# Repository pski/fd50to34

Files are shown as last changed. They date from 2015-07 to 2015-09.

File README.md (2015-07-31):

# fd50to34: Adapt 34 Pin Floppy Drives to 50 Pin Controllers
## by Mark J. Blair <nf6x@nf6x.net>

This board is a cable adapter to allow 3.5" or 5.25" floppy disk drives to be connected to computer systems with floppy disk controllers that are designed for use with 8" floppy disk drives. It is inspired by instructions by Frank Durda IV for connecting 5.25" floppy disk drives to Radio Shack/Tandy model II, 12, 16 and 6000 computers, as found at this URL:

http://nemesis.lonestar.org/computers/tandy/hardware/model16_6000/floppyfix.html

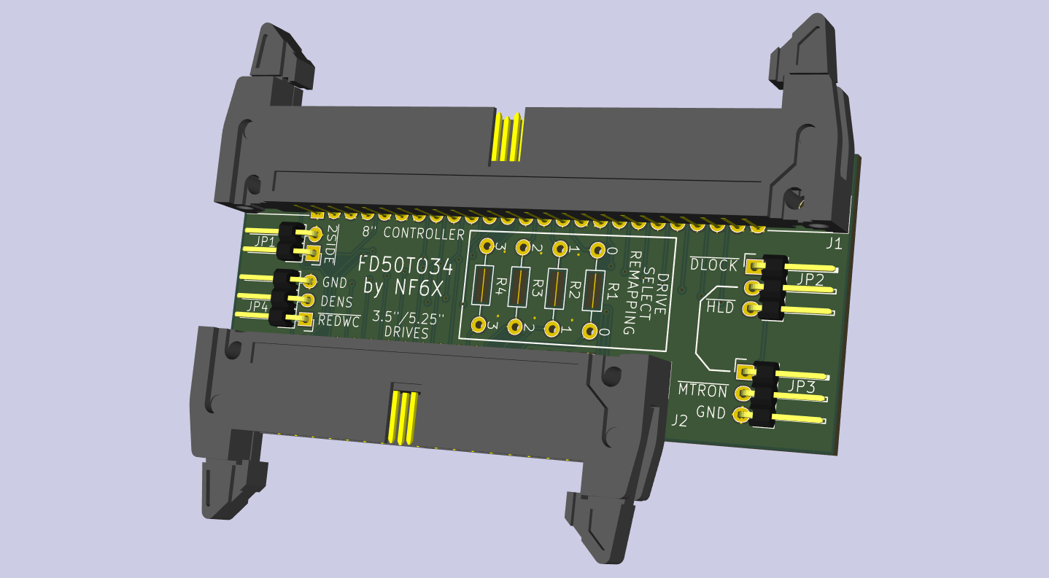
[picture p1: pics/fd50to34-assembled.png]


## Features

* Jumper-selectable double-sided disk support.
* Jumper selection allows drive motors to be strapped on all the time, or controlled by either the head load or in-use/door-lock signal.
* Bank of shorted resistor footprints allows easy drive select number remapping.
* Drive signals are labeled on bottom of board for debugging purposes.

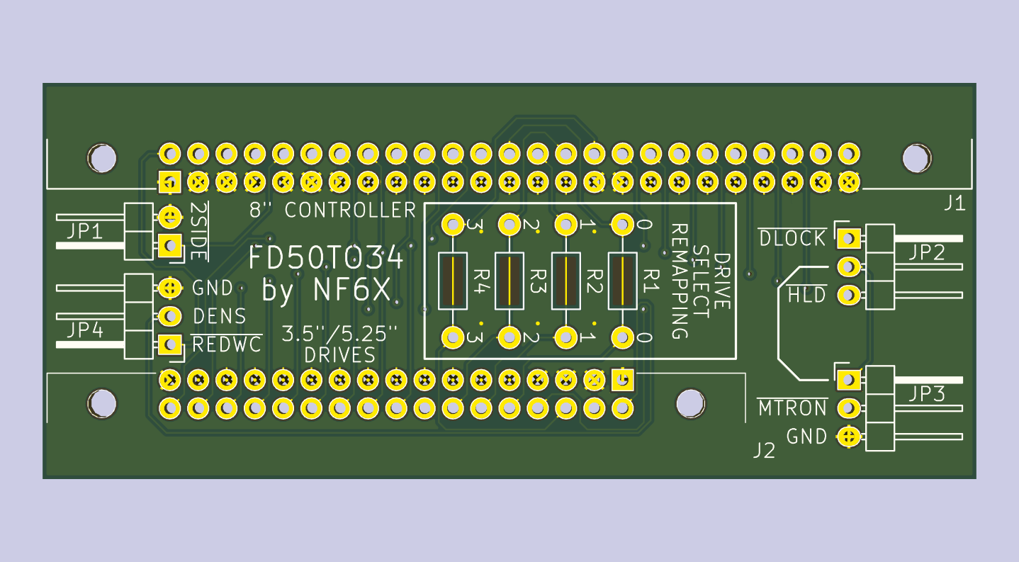
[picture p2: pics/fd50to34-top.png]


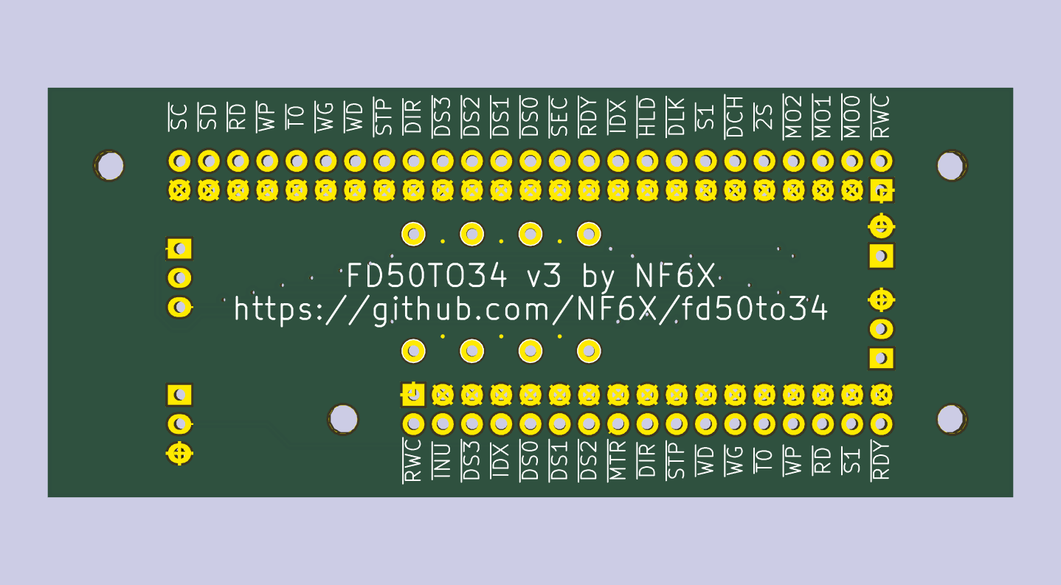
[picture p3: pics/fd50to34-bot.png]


## Schematic Diagram

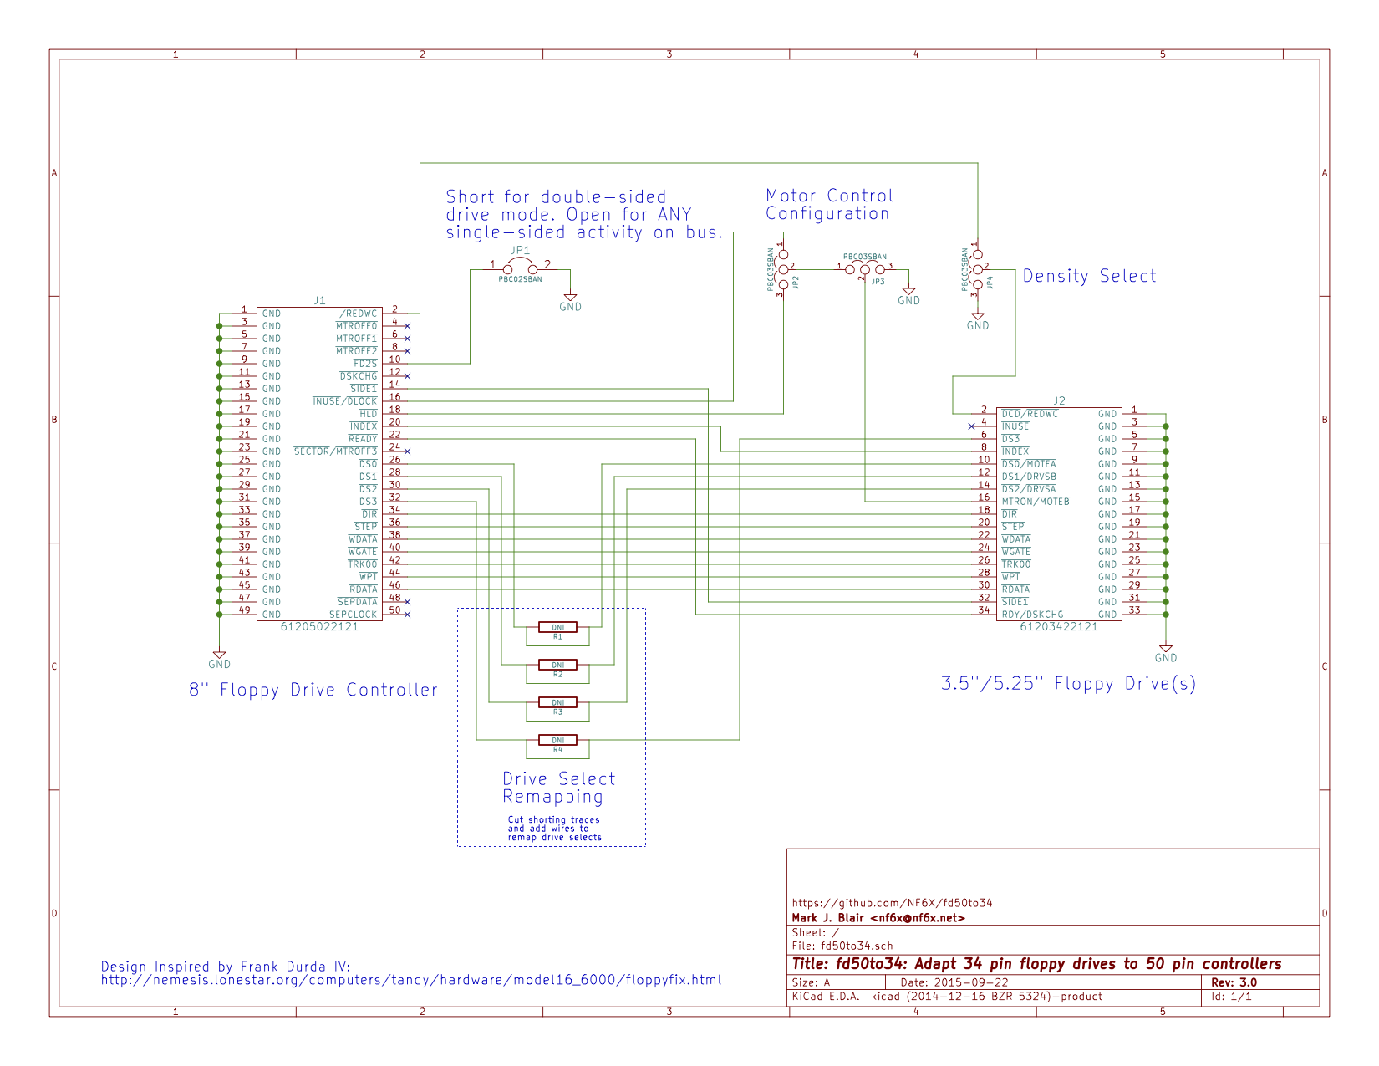
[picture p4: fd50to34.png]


## JP1: Double-Sided Media Detect

Install a jumper at JP1 to enable double-sided disk support. If any single-sided disks will be used, remove this jumper while accessing them, since installing this jumper makes the controller think that all drives are reporting double-sided media.

If desired, connect a remote SPST switch to this jumper, and close it to enable double-sided media.

## JP2 and JP3: Motor Control

Frank recommends strapping the motor control line to ground to force the drive motors on, since 8" drive motor control works differently than 3.5" and 5.25" drive interfaces expect. To get this behavior, install a jumper between pins 2 and 3 of JP3 (labeled MTRON and GND on the PCB). JP2 is ignored in this configuration.

Some drives can be configured to qualify their motor controls with the drive select signals. With these drives, you may wish to experiment with different motor control schemes. To enable these schemes, first move the jumper on JP3 to pins 1 and 2. Then, install a jumper on JP2 to connect the motor control signal to either the head load signal or the door lock signal.

When connecting a Lotharek floppy drive emulator to a TRS-80 Model II/12/16/6000, the door lock signal seems to work well for drive motor control. For this configuration, install a jumper between pins 1 and 2 of JP2, and another jumper between pins 1 and 2 of JP3.

## JP4: Density Select

Some floppy drives use J2 pin 2 to select different density modes. On compatible 3.5" drives, pulling this pin down will select a 360 RPM mode which may work well on systems expecting 8" floppy drives. To do this, install a jumper between pins 2 and 3 of JP4. Install no jumper on JP4 for default behavior.

Installing a jumper between pins 1 and 2 connects the reduced write current signal on the 8" interface to J2 pin 2, which is also used to select reduced write current on some 5.25" drives. This option is experimental. 

## R1-R4: Drive Select Remapping

If you need to remap the drive select signals, first cut the exposed traces on the top side of the board which short out resistors R1 through R4 (which are not normally installed). Then, solder wires between the pads of R1-R4 to map the drive select signals as needed.

## Suggested Parts

Refs    | Manufacturer | Part Number  | Comments
--------|--------------|--------------|---------------
J1      | Wurth        | 61205022121  |
J2      | Wurth        | 61203422121  |
JP1-JP4 | Sullins      | PBC36SBAN    | Cut to length
Jumpers | Sullins      | QPC02SXGN-RC |

## About the Design

This board was designed in Kicad 2014-12-16 BZR 5324 on a Mac.
Design rules are 6 mil line, 6 mil trace, 13 mil via hole. It is suitable for fabrication at OSH Park.

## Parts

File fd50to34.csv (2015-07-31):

Reference | Quantity | Value | Footprint | Datasheet | PartNum
J1 | 1 | FD50 | NF6X_Connectors:Wurth_61205022121 |  | 61205022121
J2 | 1 | FD34 | NF6X_Connectors:Wurth_61203422121 |  | 61203422121
JP1 | 1 | JUMPER | Pin_Headers:Pin_Header_Angled_1x02
JP2 JP3 JP4 | 3 | JUMPER3 | Pin_Headers:Pin_Header_Angled_1x03
R1 R2 R3 R4 | 4 | 0 | Resistors_ThroughHole:Resistor_Horizontal_RM10mm

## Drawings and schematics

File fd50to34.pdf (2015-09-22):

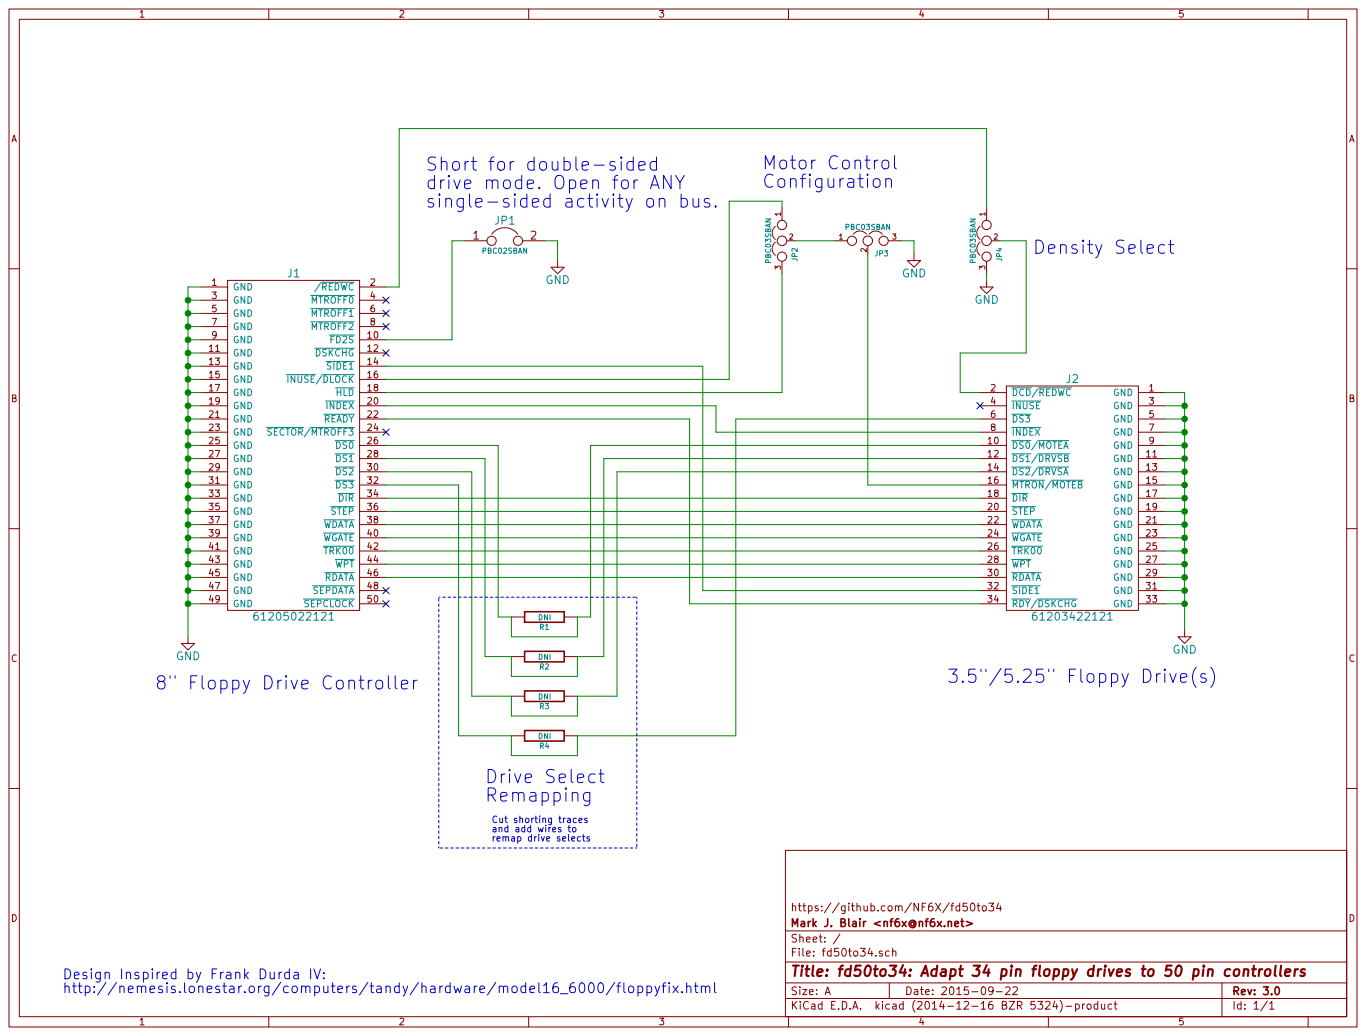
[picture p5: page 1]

Short for double-sided
drive mode. Open for ANY
single-sided activity on bus.

R1 DNI R2 DNI R3 DNI R4 DNI Drive Select

Cut shorting traces and add wires to
remap drive selects

https://github.com/NF6X/fd50to34
File: fd50to34.sch Sheet: / Mark J. Blair <nf6x@nf6x.net>

Design Inspired by Frank Durda IV:
http://nemesis.lonestar.org/computers/tandy/hardware/model16_6000/floppyfix.html

Id: 1/1 Title: fd50to34: Adapt 34 pin floppy drives to 50 pin controllers

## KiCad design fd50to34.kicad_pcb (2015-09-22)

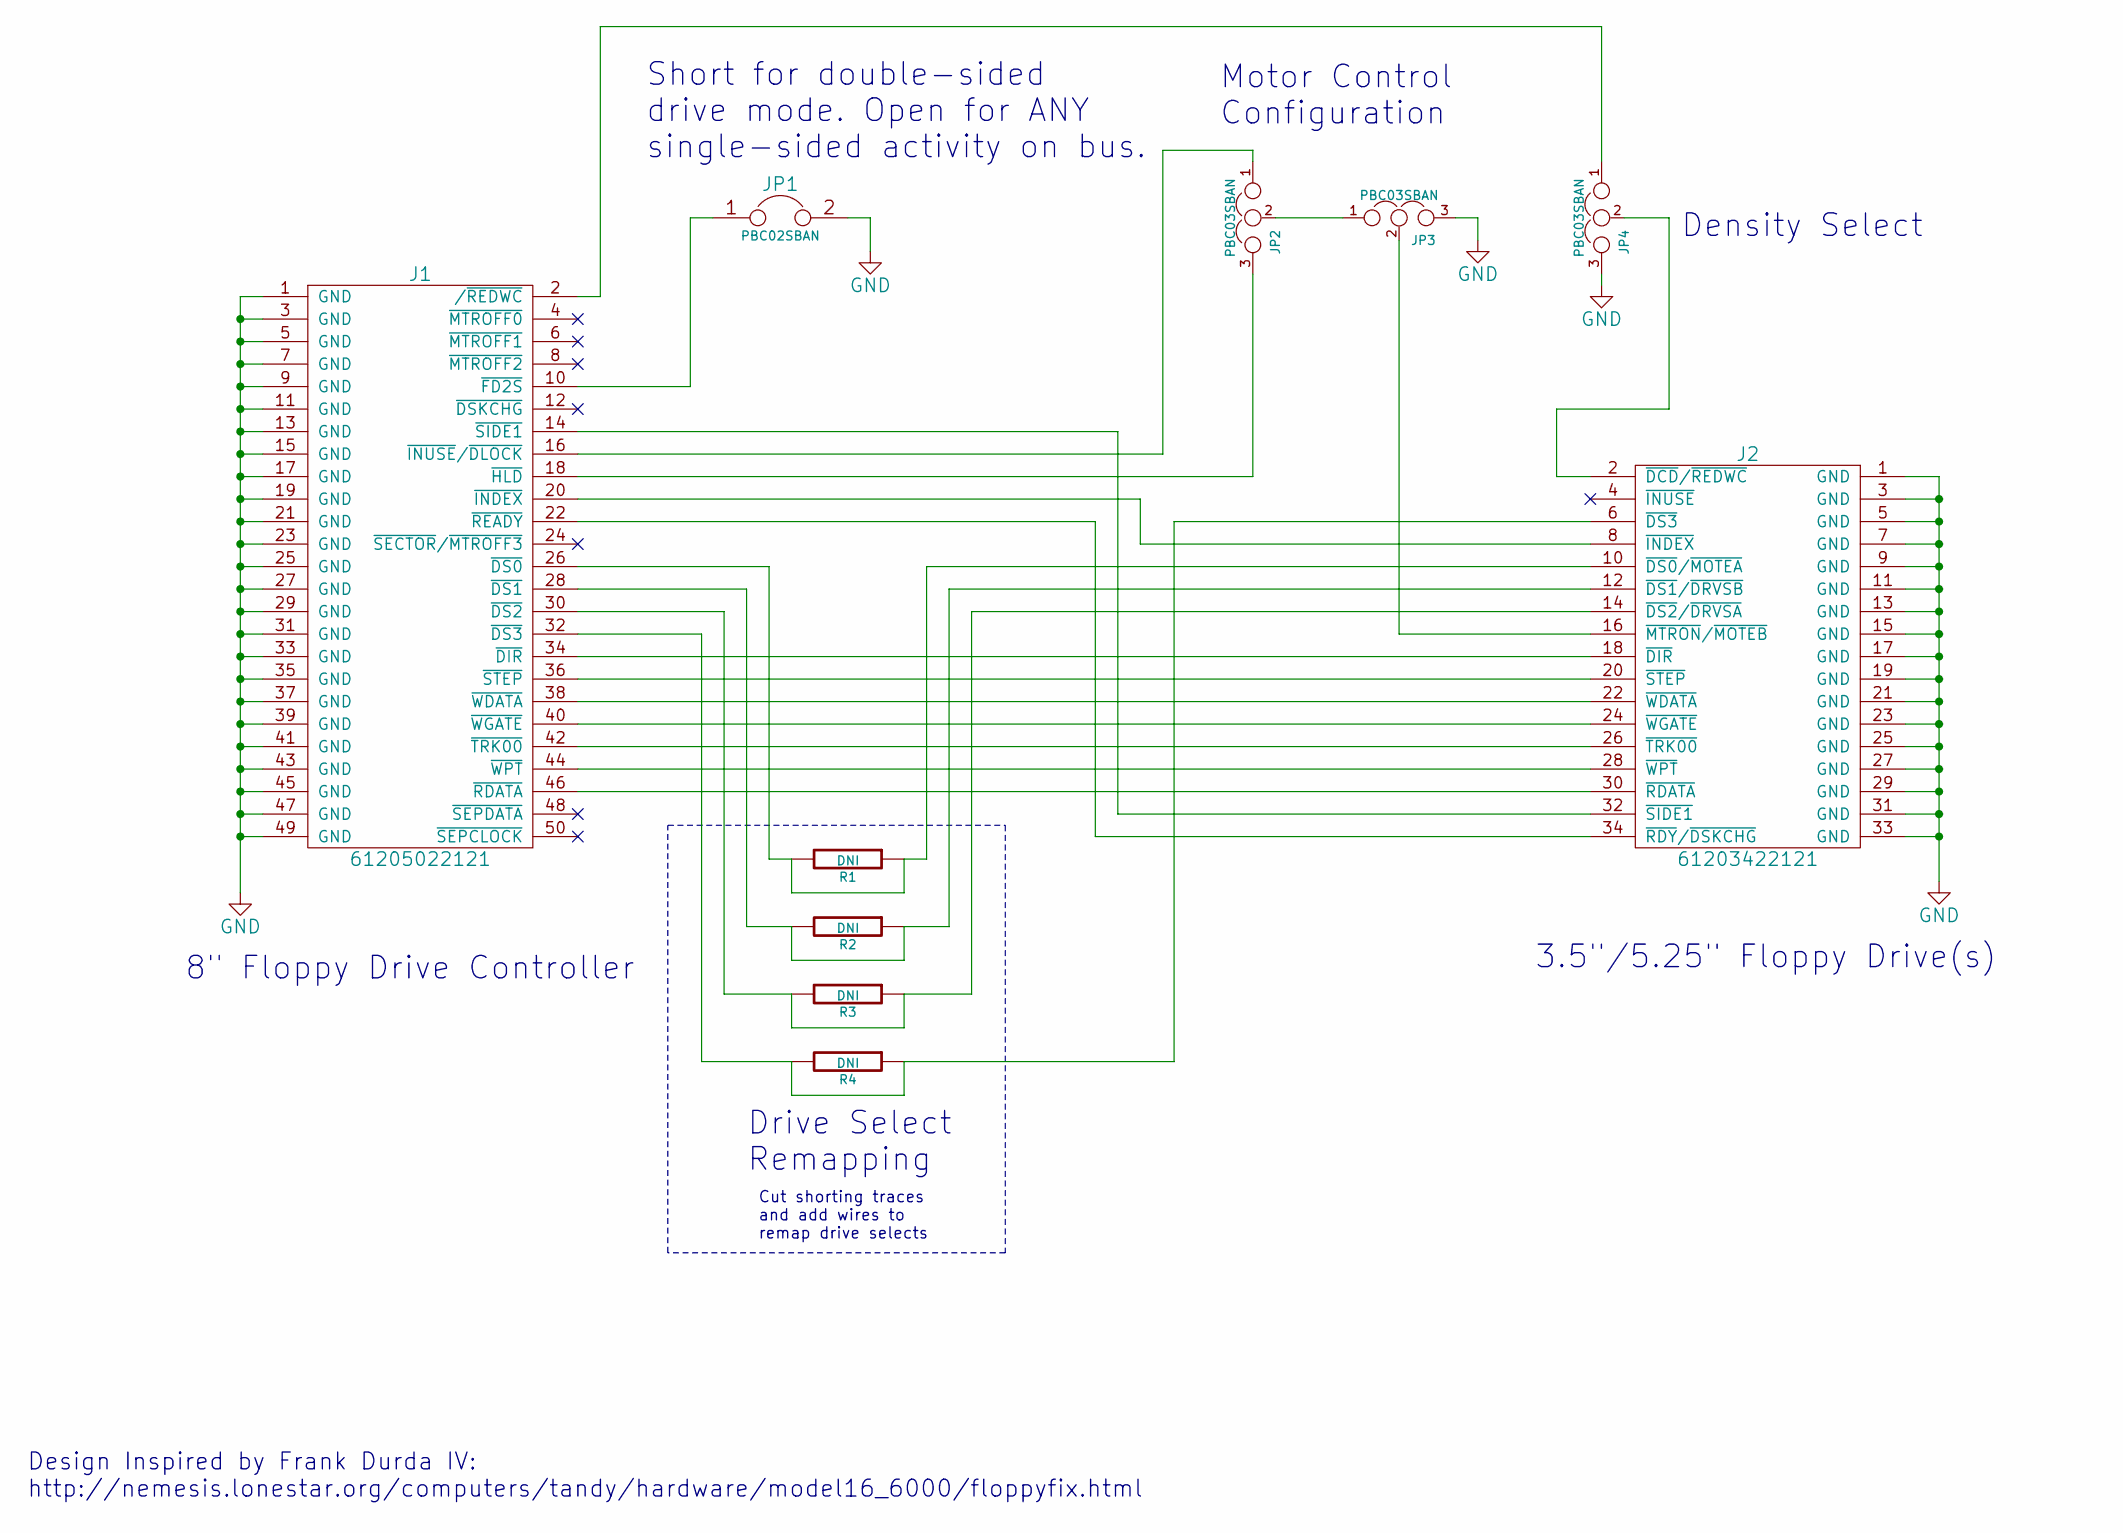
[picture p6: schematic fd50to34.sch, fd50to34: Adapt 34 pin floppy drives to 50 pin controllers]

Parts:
J1: 61205022121; Wurth_61205022121; PartNum 61205022121
J2: 61203422121; Wurth_61203422121; PartNum 61203422121
JP1: PBC02SBAN; Pin_Header_Angled_1x02
JP2, JP3, JP4: PBC03SBAN; Pin_Header_Angled_1x03
R1, R2, R3, R4: DNI; Resistor_Horizontal_RM10mm

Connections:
GND: J1.1 (GND), J1.3 (GND), J1.5 (GND), J1.7 (GND), J1.9 (GND), J1.11 (GND), J1.13 (GND), J1.15 (GND), J1.17 (GND), J1.19 (GND), J1.21 (GND), J1.23 (GND), J1.25 (GND), J1.27 (GND), J1.29 (GND), J1.31 (GND), J1.33 (GND), J1.35 (GND), J1.37 (GND), J1.39 (GND), J1.41 (GND), J1.43 (GND), J1.45 (GND), J1.47 (GND), J1.49 (GND), J2.1 (GND), J2.3 (GND), J2.5 (GND), J2.7 (GND), J2.9 (GND), J2.11 (GND), J2.13 (GND), J2.15 (GND), J2.17 (GND), J2.19 (GND), J2.21 (GND), J2.23 (GND), J2.25 (GND), J2.27 (GND), J2.29 (GND), J2.31 (GND), J2.33 (GND), JP1.2, JP3.3, JP4.3
unnamed: J1.2 (/~REDWC), JP4.1
unnamed: J1.10 (~FD2S), JP1.1
unnamed: J1.14 (~SIDE1), J2.32 (~SIDE1)
unnamed: J1.16 (~INUSE~/~DLOCK), JP2.1
unnamed: J1.18 (~HLD), JP2.3
unnamed: J1.20 (~INDEX), J2.8 (~INDEX)
unnamed: J1.22 (~READY), J2.34 (~RDY~/~DSKCHG)
unnamed: J1.26 (~DS0), J2.10 (~DS0~/~MOTEA), R1.1, R1.2
unnamed: J1.28 (~DS1), J2.12 (~DS1~/~DRVSB), R2.1, R2.2
unnamed: J1.30 (~DS2), J2.14 (~DS2~/~DRVSA), R3.1, R3.2
unnamed: J1.32 (~DS3), J2.6 (~DS3), R4.1, R4.2
unnamed: J1.34 (~DIR), J2.18 (~DIR)
unnamed: J1.36 (~STEP), J2.20 (~STEP)
unnamed: J1.38 (~WDATA), J2.22 (~WDATA)
unnamed: J1.40 (~WGATE), J2.24 (~WGATE)
unnamed: J1.42 (~TRK00), J2.26 (~TRK00)
unnamed: J1.44 (~WPT), J2.28 (~WPT)
unnamed: J1.46 (~RDATA), J2.30 (~RDATA)
unnamed: J2.2 (~DCD~/~REDWC), JP4.2
unnamed: J2.16 (~MTRON~/~MOTEB), JP3.2
unnamed: JP2.2, JP3.1

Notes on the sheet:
8" Floppy Drive Controller
3.5"/5.25" Floppy Drive(s)
Short for double-sided drive mode. Open for ANY single-sided activity on bus.
Motor Control Configuration
Drive Select Remapping
Design Inspired by Frank Durda IV: http://nemesis.lonestar.org/computers/tandy/hardware/model16_6000/floppyfix.html
Cut shorting traces and add wires to remap drive selects
Density Select

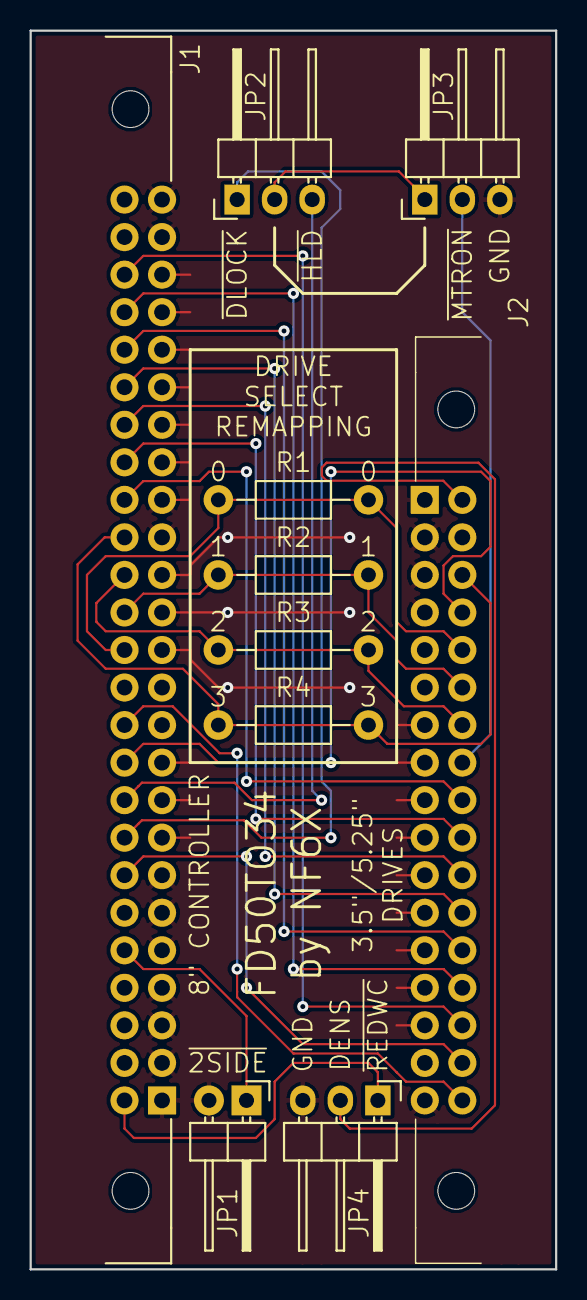
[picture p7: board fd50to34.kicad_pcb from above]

Board: 2 copper layers, 35.6 x 83.8 mm, 10 parts (0 on the bottom side), 22 nets.

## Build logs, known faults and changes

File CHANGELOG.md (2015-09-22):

# v3.0 OSHW Logo Removal

* Removed OSHW logo from PCB silkscreen.

# v2.1 MacroFab updates

* Revised component values for MacroFab BOM extraction.

# v2 PCB changes

* Silkscreen correction.
* Added jumper for 5.25" REDWC/DensitySel/DCD pin.

# v1 PCB

* Initial release.

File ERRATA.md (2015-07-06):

# v1 PCB Errata

* Dyslexia in the top silkscreen: Board name is incorrect.

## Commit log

2015-07-06 Initial commit.
    [fd50to34-B_Cu.gbr, fd50to34-B_Mask.gbr, fd50to34-B_SilkS.gbr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]
2015-07-06 Added PCB renderings.
2015-07-06 Added reference to schematic diagram.
2015-07-06 Added PNG version of schematic for inline display in README.md.
2015-07-06 Corrected gerber origin.
    [fd50to34-B_Cu.gbr, fd50to34-B_Mask.gbr, fd50to34-B_SilkS.gbr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]
2015-07-06 Added errata and changelog file. Corrected top silkscreen typo on PCB. Incremented PCB version to v2. Updated schematic version to 2.0-DRAFT.
    [fd50to34-B_Cu.gbr, fd50to34-B_Mask.gbr, fd50to34-B_SilkS.gbr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]
2015-07-07 Added library cache and BOM XML file to repo.
2015-07-31 Added density select jumper.
    [fd50to34-B_Cu.gbr, fd50to34-B_Mask.gbr, fd50to34-B_SilkS.gbr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]
2015-08-19 Revised part numbers for production quote at MacroFab.
    [fd50to34.kicad_pcb, fd50to34.sch]
2015-09-22 Removed OSHW logo.
    [fd50to34-B_Cu.gbr, fd50to34-B_Mask.gbr, fd50to34-B_SilkS.gbr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]
2015-09-22 Schematic PNG regenerated.
2015-09-22 Fixed bad drill file configuration settings.
    [fd50to34.kicad_pcb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]
